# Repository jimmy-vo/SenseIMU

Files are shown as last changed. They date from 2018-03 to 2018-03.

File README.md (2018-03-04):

# SenseIMU
Control a mouse by human gesture via Bluetooth - A demonstration of Kalman Filter and other different optimization and estimation approaches.

## Input
* Accelerometer raw data
* Gyroscope raw data
* Magnetometer raw data

## Output
* Estimated Euler angles
* Estimated Quaternion set
* Represent object orientation on 3D Winform application
* Control mouse using estimated Euler angles via Bluetooth

## Functionality
* Bluetooth Connection
* Data plotting, 3D rendering
* Switching between different algorithms:
  - Tilt-compensation Method  
  - Gauss Newton Method 
  - AHRS
  - Quaternion based – gyro bias – EKF 
  - Quaternion based – gyro rate – EKF
  - DCM based KF 

## Screenshot

### HW Assembly  

<p>
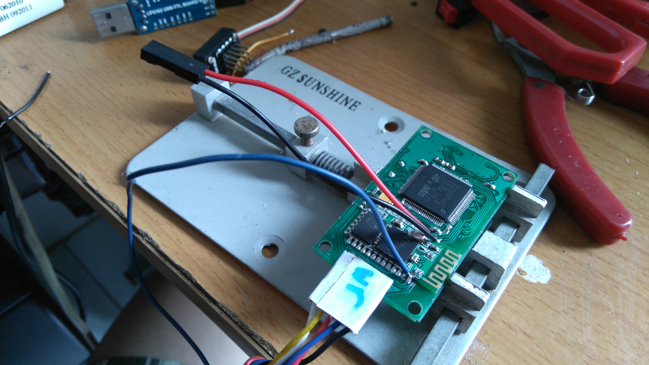
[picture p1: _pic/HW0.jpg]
  
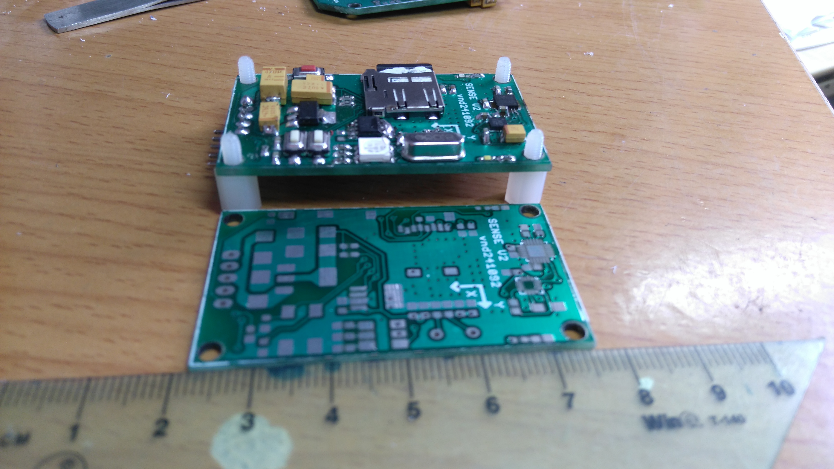
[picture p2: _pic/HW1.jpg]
  
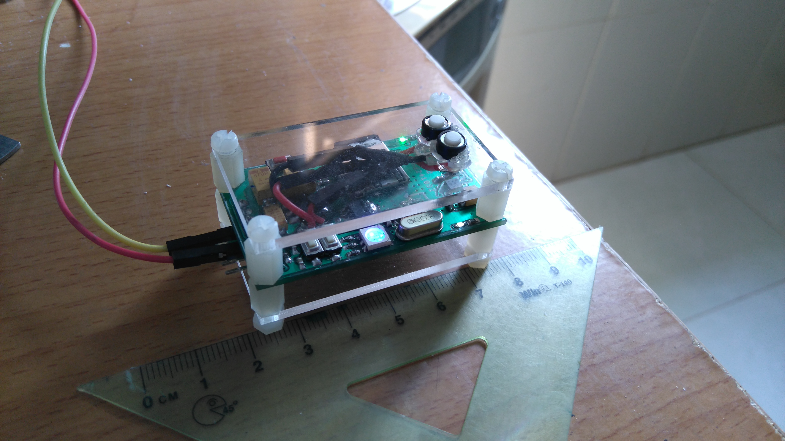
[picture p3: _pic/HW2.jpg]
  
</p>

### Demonstration  
<p>
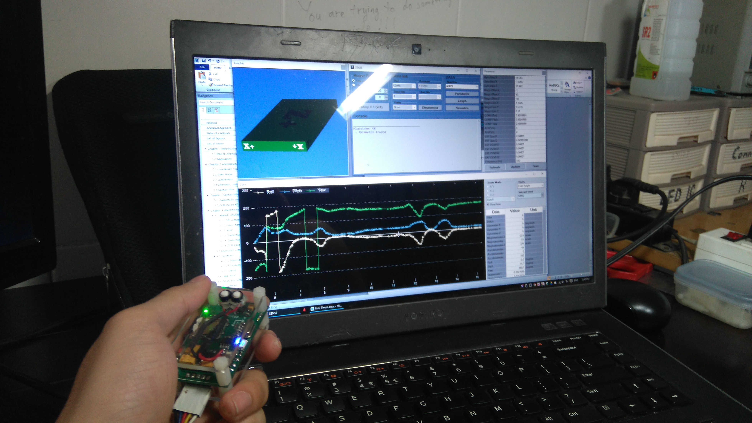
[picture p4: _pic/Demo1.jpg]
  
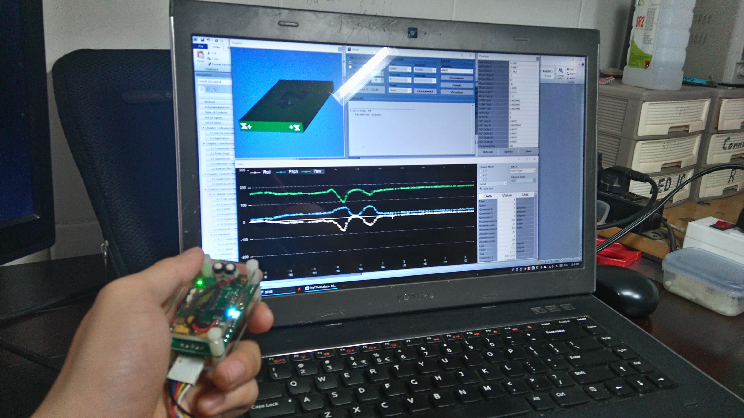
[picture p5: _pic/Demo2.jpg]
  
</p>

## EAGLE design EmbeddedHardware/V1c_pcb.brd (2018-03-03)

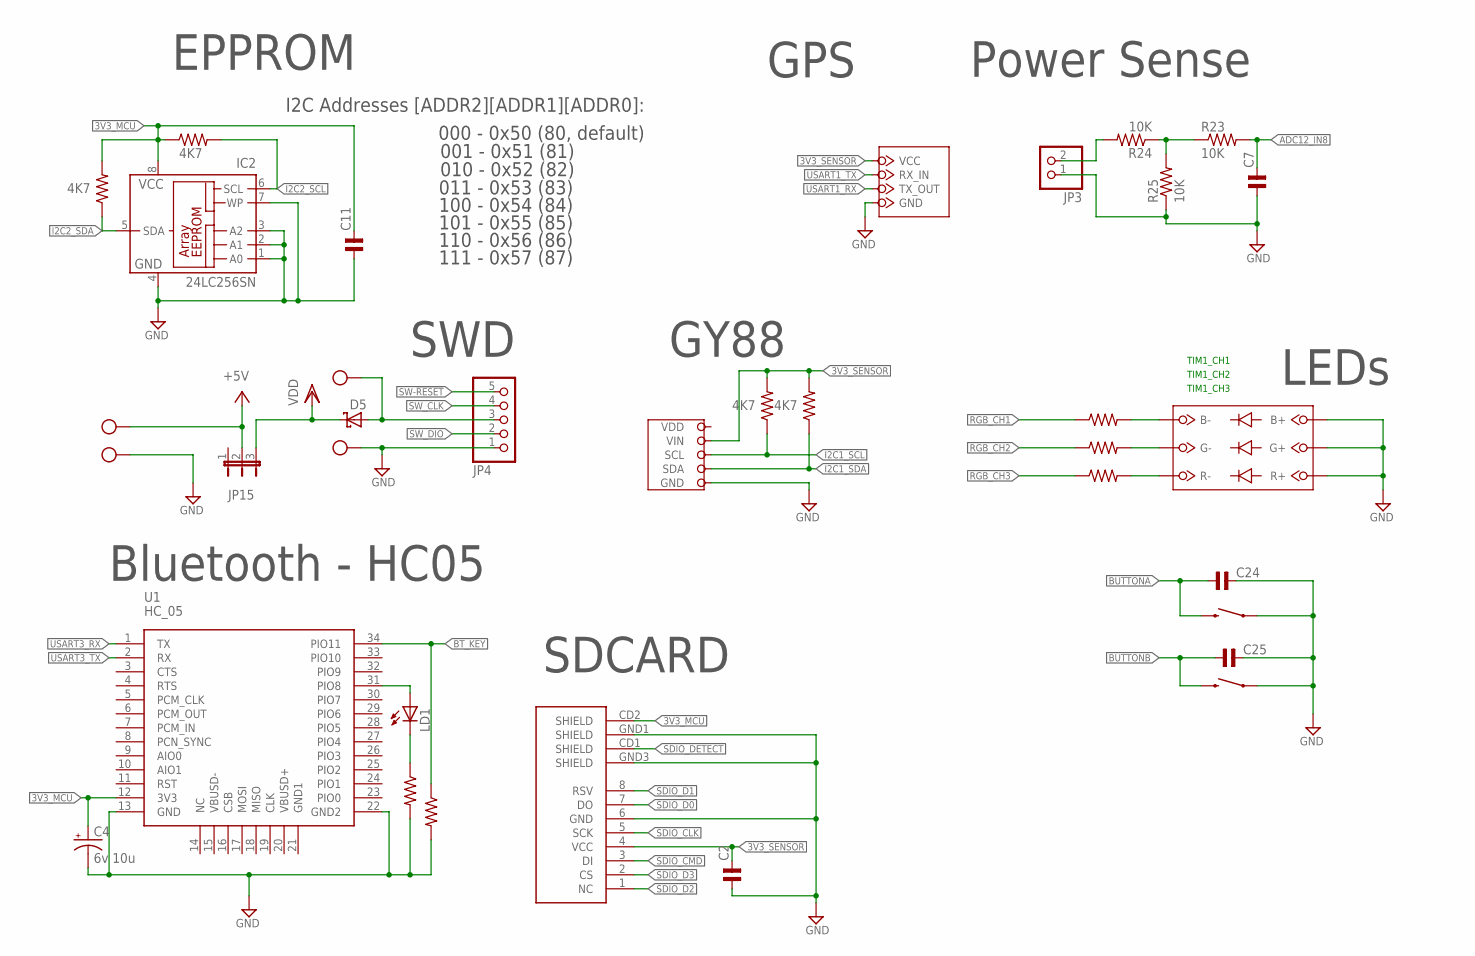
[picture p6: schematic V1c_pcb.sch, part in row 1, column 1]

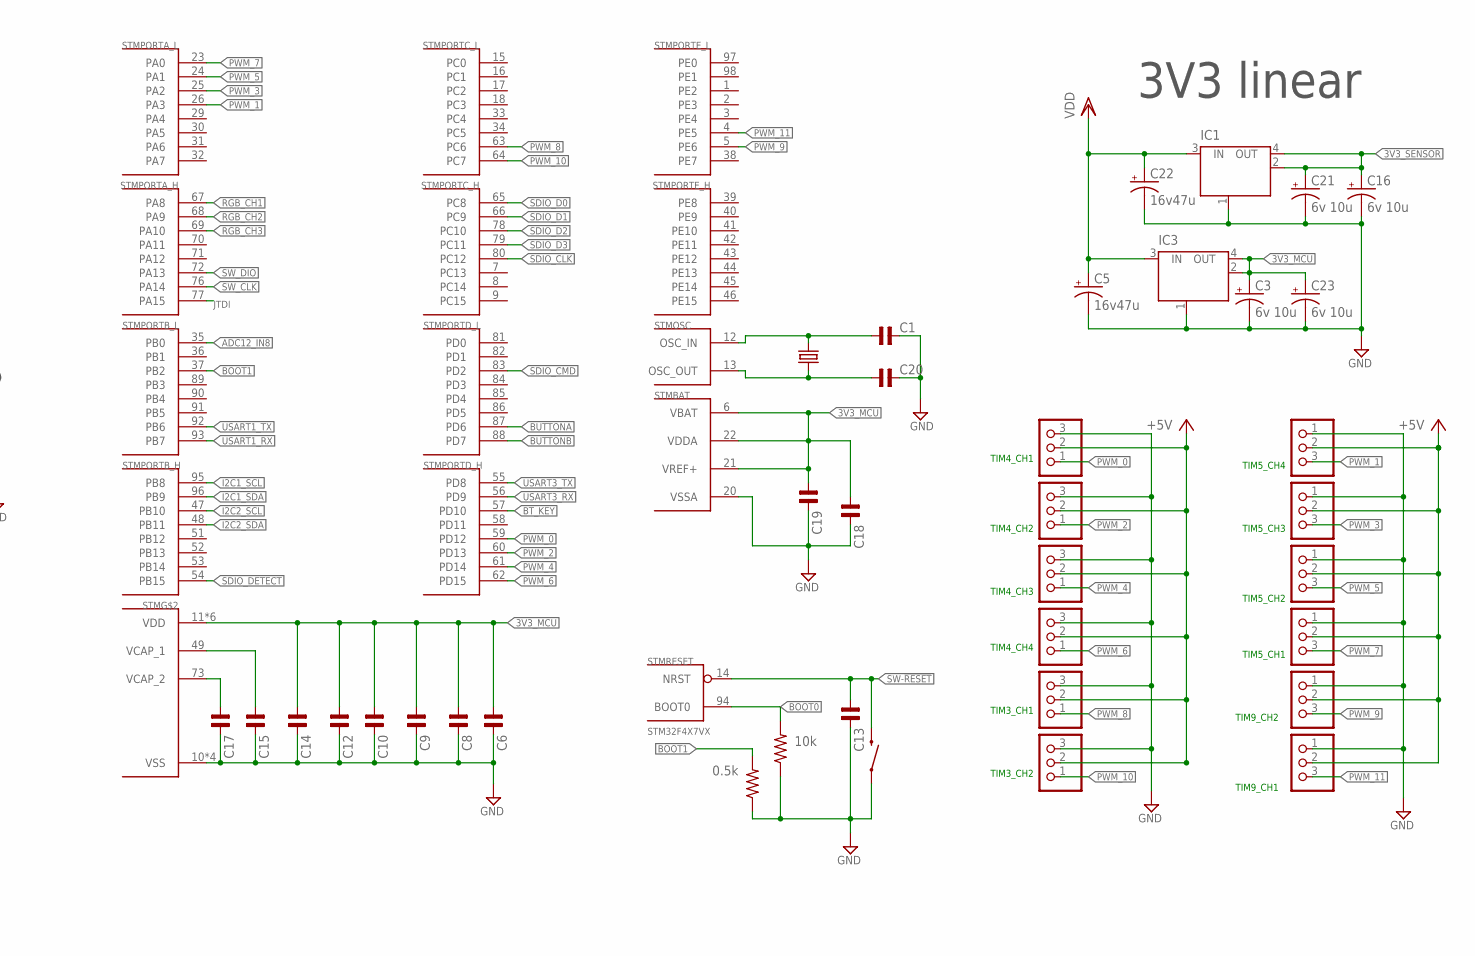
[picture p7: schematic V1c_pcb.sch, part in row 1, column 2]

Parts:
C1, C2, C6, C7, C8, C9, C10, C11, C12, C13, C14, C15, C17, C18, C19, C20, C24, C25: C-NP-SMD-0603; C-0603
C3, C4, C16, C21, C23: 6v 10u; SMC_A
C5, C22: 16v47u; SMC_C
D5: MBRS330T3; SMC
IC1, IC3: LINEAR_MC33269ST-3.3T3; LINEAR_SOT223
IC2: 24LC256SN; SO-08; DIGIKEY 24LC256-E/SN-ND
JP1, JP2, JP5, JP6, JP7, JP8, JP9, JP10, JP11, JP12, JP13, JP14: PINHD-1X3_2.54-90°; 1X03/90
JP3: PINHD-1X2; 1X02
JP4: PINHD-1X5_2.54-90°; 1X05/90
JP15: JP2E; JP2
LD1: LEDCHIPLED_0805; CHIPLED_0805
R1, R4, R15, R16: 4K7; SPARKFUN_0603-RES
R2, R3, R5, R6, R9, R23, R24, R25: 10K; SPARKFUN_0603-RES
R7: 10k; SPARKFUN_0603-RES
R8: 0.5k; SPARKFUN_0603-RES
S1, S2, S3: RESET; TACTILE-SWITCH-1101NE; PARTNO EVQ-P7J01P
SDCARD2: microSD Socket; MICRO-SD-SOCKET-PP
STM: STM32F4X7VX; TQFP100; PARTNO STM32F427VI
U1: HC_05; BLUETOOTH_SMD
U$1: GY-88; BREAKOUT
U$10: GPS_MODULE; 23X30
U$12: RGB_LED; SMD
X1, X2: MKDSN1,5/2-5,08
Y1: CRYSTALHC49US; HC49US

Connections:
3V3_MCU: C3.+, C4.+, C6.1, C8.1, C9.1, C10.1, C11.2, C12.1, C14.1, C18.1, C19.1, C23.+, IC2.8 (VCC), IC3.2 (OUT), IC3.4 (OUT), R15.1, R16.2, SDCARD2.CD2 (SHIELD), STM.6 (VBAT), STM.11 (VDD), STM.19 (VDD), STM.21 (VREF+), STM.22 (VDDA), STM.28 (VDD), STM.50 (VDD), STM.75 (VDD), STM.100 (VDD), U1.12 (3V3)
3V3_SENSOR: C2.2, C16.+, C21.+, IC1.2 (OUT), IC1.4 (OUT), R1.2, R4.2, SDCARD2.4 (VCC), U$1.2 (VIN), U$10.4 (VCC)
+5V: JP1.2, JP2.2, JP5.2, JP6.2, JP7.2, JP8.2, JP9.2, JP10.2, JP11.2, JP12.2, JP13.2, JP14.2, JP15.2, X2.2
ADC12_IN8: C7.2, R23.2, STM.35 (PB0)
BOOT0: R7.2, STM.94 (BOOT0)
BOOT1: R8.2, STM.37 (PB2)
BT_KEY: R5.1, STM.57 (PD10), U1.34 (PIO11)
BUTTONA: C24.1, S3.P$2 (2), STM.87 (PD6)
BUTTONB: C25.1, S2.P$2 (2), STM.88 (PD7)
GND: C1.2, C2.1, C3.-, C4.-, C5.-, C6.2, C7.1, C8.2, C9.2, C10.2, C11.1, C12.2, C13.2, C14.2, C15.2, C16.-, C17.2, C18.2, C19.2, C20.2, C21.-, C22.-, C23.-, C24.2, C25.2, IC1.1 (GND/ADJ), IC2.1 (A0), IC2.2 (A1), IC2.3 (A2), IC2.4 (GND), IC2.7 (WP), IC3.1 (GND/ADJ), JP1.1, JP2.1, JP3.1, JP4.1, JP5.1, JP6.1, JP7.3, JP8.1, JP9.3, JP10.3, JP11.1, JP12.3, JP13.3, JP14.3, R5.2, R7.1, R8.1, R9.2, R25.1, S1.P$1 (1), S2.P$1 (1), S3.P$1 (1), SDCARD2.6 (GND), SDCARD2.GND1 (SHIELD), SDCARD2.GND3 (SHIELD), STM.10 (VSS), STM.20 (VSSA), STM.27 (VSS), STM.74 (VSS), STM.99 (VSS), U1.13 (GND), U1.22 (GND2), U$1.3 (GND), U$10.1 (GND), U$12.B+, U$12.G+, U$12.R+, X1.2, X2.1
I2C1_SCL: R1.1, STM.95 (PB8), U$1.4 (SCL)
I2C1_SDA: R4.1, STM.96 (PB9), U$1.5 (SDA)
I2C2_SCL: IC2.6 (SCL), R15.2, STM.47 (PB10)
I2C2_SDA: IC2.5 (SDA), R16.1, STM.48 (PB11)
JTDI: STM.77 (PA15)
unnamed: C1.1, STM.12 (OSC_IN), Y1.2
unnamed: R2.2, U$12.B-
unnamed: JP3.2, R24.2
unnamed: LD1.A, U1.31 (PIO8)
unnamed: LD1.C, R9.1
unnamed: R3.2, U$12.G-
unnamed: R6.2, U$12.R-
unnamed: D5.A, JP4.3, X1.1
unnamed: R23.1, R24.1, R25.2
unnamed: C20.1, STM.13 (OSC_OUT), Y1.1
unnamed: C17.1, STM.73 (VCAP_2)
unnamed: C15.1, STM.49 (VCAP_1)
PWM_0: JP7.1, STM.59 (PD12)
PWM_1: JP6.3, STM.26 (PA3)
PWM_2: JP9.1, STM.60 (PD13)
PWM_3: JP11.3, STM.25 (PA2)
PWM_4: JP10.1, STM.61 (PD14)
PWM_5: JP5.3, STM.24 (PA1)
PWM_6: JP12.1, STM.62 (PD15)
PWM_7: JP1.3, STM.23 (PA0)
PWM_8: JP13.1, STM.63 (PC6)
PWM_9: JP8.3, STM.5 (PE6)
PWM_10: JP14.1, STM.64 (PC7)
PWM_11: JP2.3, STM.4 (PE5)
RGB_CH1: R2.1, STM.67 (PA8)
RGB_CH2: R3.1, STM.68 (PA9)
RGB_CH3: R6.1, STM.69 (PA10)
SDIO_CLK: SDCARD2.5 (SCK), STM.80 (PC12)
SDIO_CMD: SDCARD2.3 (DI), STM.83 (PD2)
SDIO_D0: SDCARD2.7 (DO), STM.65 (PC8)
SDIO_D1: SDCARD2.8 (RSV), STM.66 (PC9)
SDIO_D2: SDCARD2.1 (NC), STM.78 (PC10)
SDIO_D3: SDCARD2.2 (CS), STM.79 (PC11)
SDIO_DETECT: SDCARD2.CD1 (SHIELD), STM.54 (PB15)
SW-!RESET: C13.1, JP4.5, S1.P$2 (2), STM.14 (NRST)
SW_CLK: JP4.4, STM.76 (PA14)
SW_DIO: JP4.2, STM.72 (PA13)
USART1_RX: STM.93 (PB7), U$10.2 (TX_OUT)
USART1_TX: STM.92 (PB6), U$10.3 (RX_IN)
USART3_RX: STM.56 (PD9), U1.1 (TX)
USART3_TX: STM.55 (PD8), U1.2 (RX)
VDD: C5.+, C22.+, D5.C, IC1.3 (IN), IC3.3 (IN), JP15.3

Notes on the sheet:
SWD
LEDs
GPS
GY88
TIM5_CH1
TIM5_CH2
TIM1_CH1
TIM1_CH2
TIM1_CH3
TIM4_CH1
TIM4_CH2
I2C Addresses [ADDR2][ADDR1][ADDR0]:
000 - 0x50 (80, default)
001 - 0x51 (81)
010 - 0x52 (82)
011 - 0x53 (83)
100 - 0x54 (84)
101 - 0x55 (85)
110 - 0x56 (86)
111 - 0x57 (87)
EPPROM
TIM5_CH3
TIM5_CH4
Bluetooth - HC05
SDCARD
Power Sense
TIM4_CH4
TIM4_CH3
TIM9_CH2
TIM9_CH1
TIM3_CH1
TIM3_CH2
3V3 linear

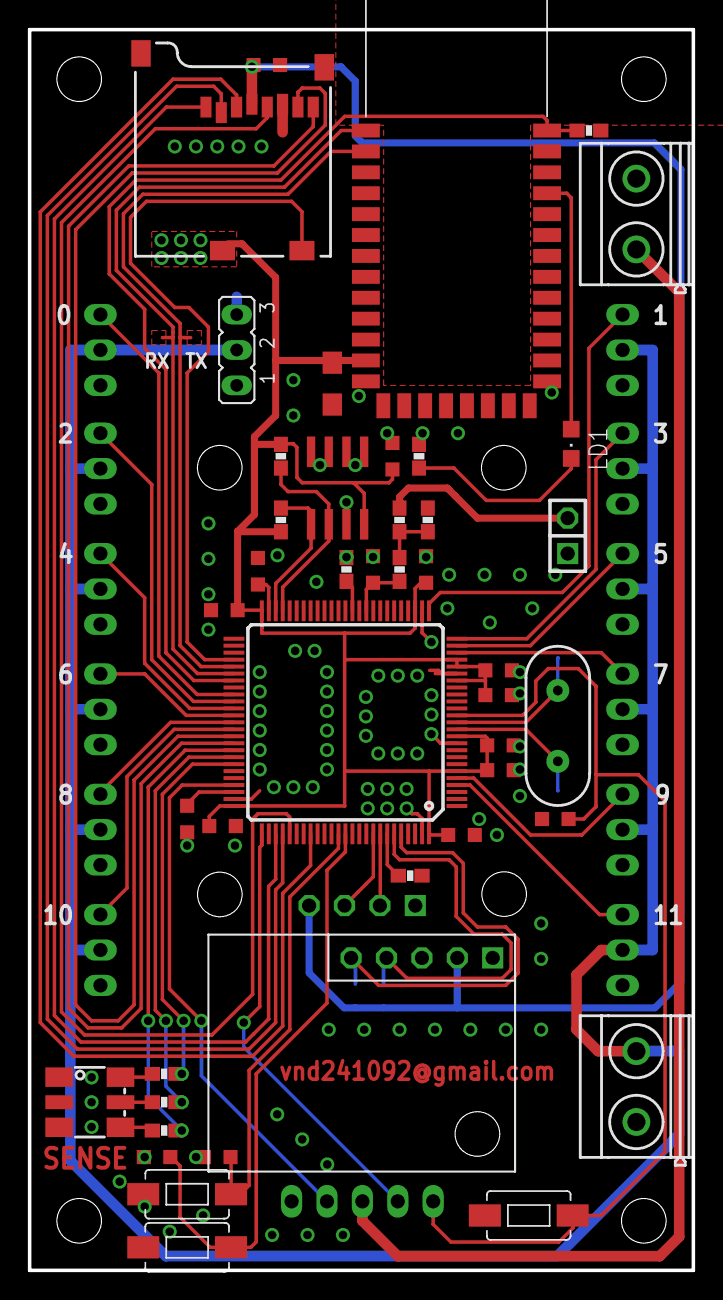
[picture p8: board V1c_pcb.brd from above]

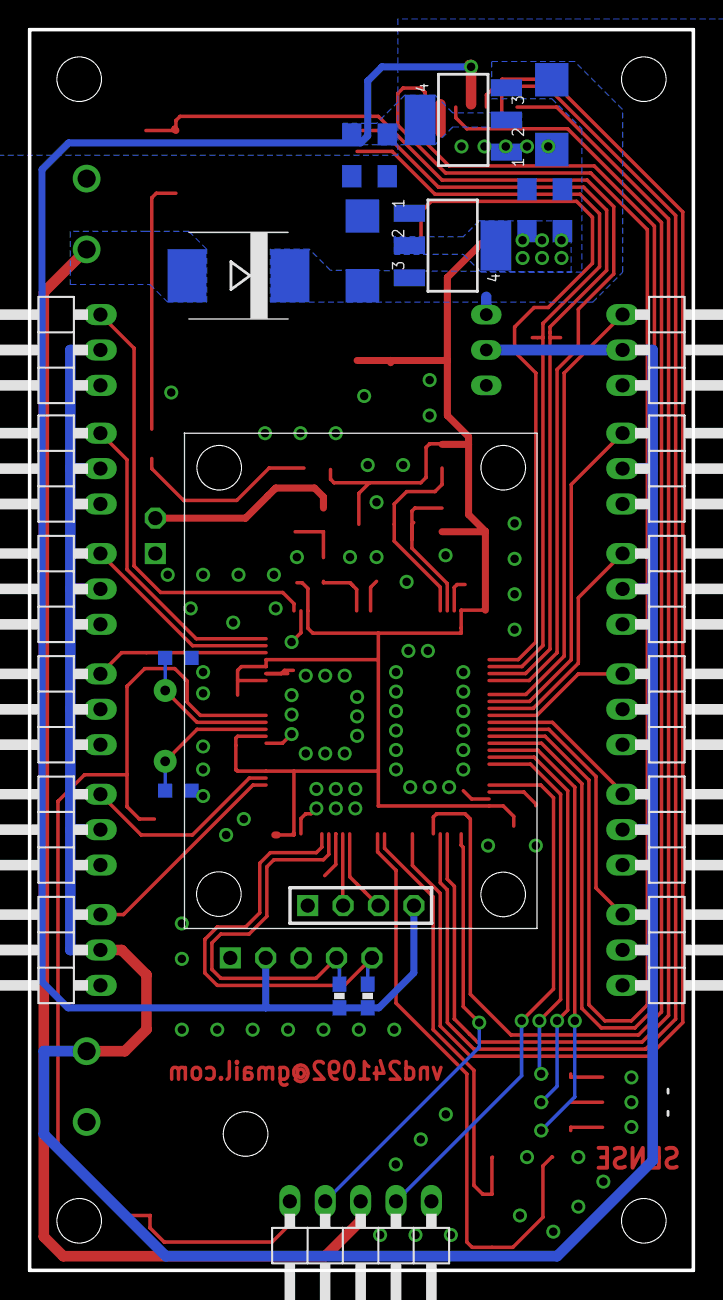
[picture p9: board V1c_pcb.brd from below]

Board: 2 copper layers, 47.6 x 89.0 mm, 71 parts (27 on the bottom side), 56 nets.

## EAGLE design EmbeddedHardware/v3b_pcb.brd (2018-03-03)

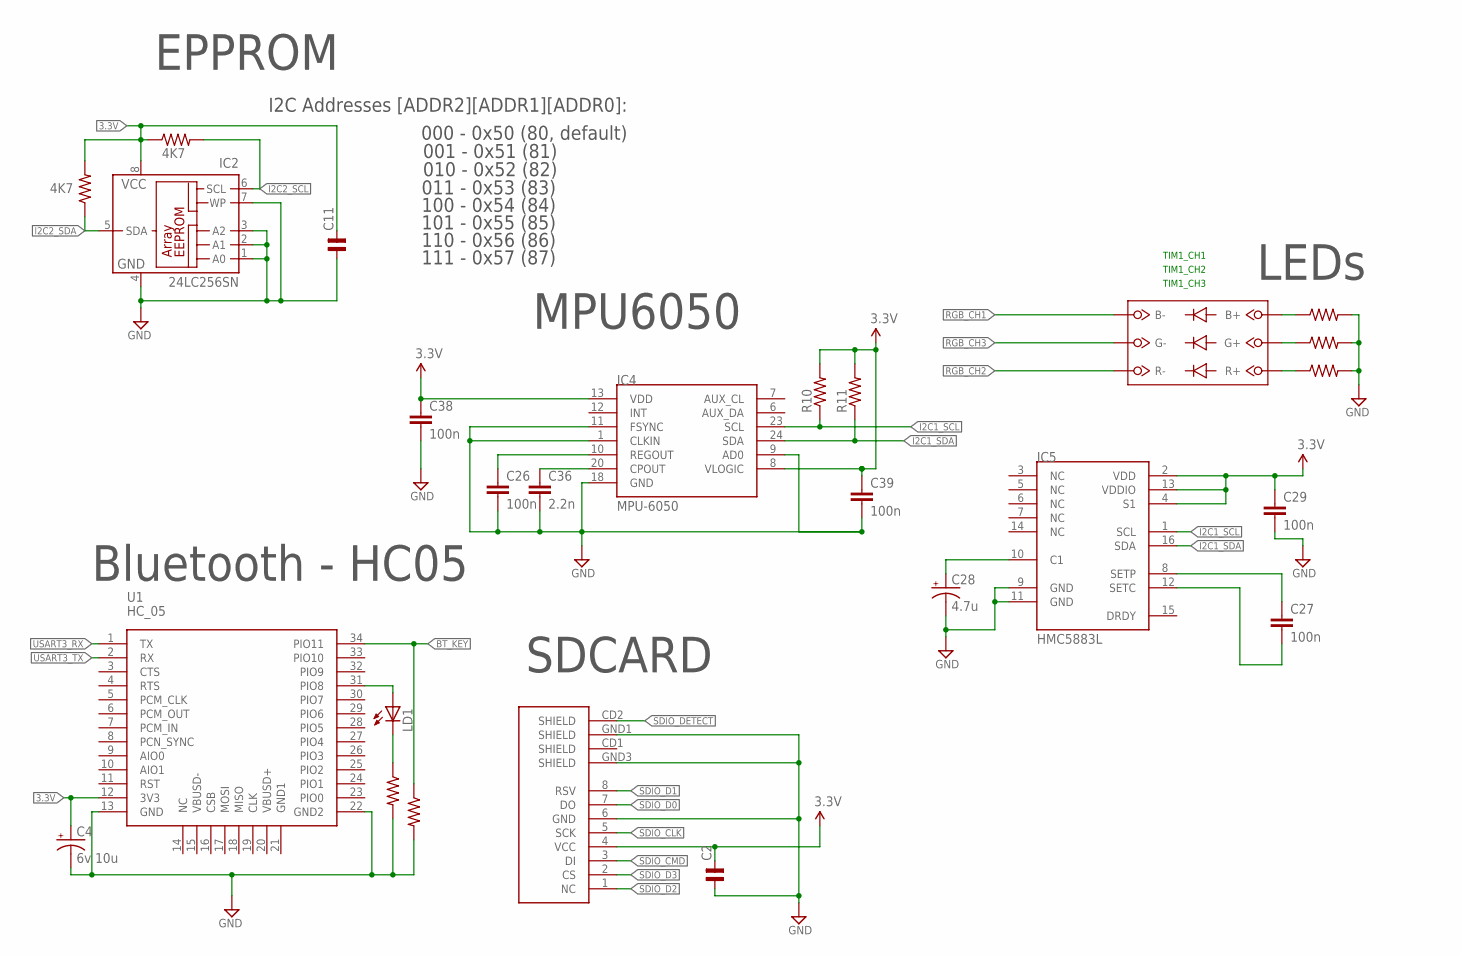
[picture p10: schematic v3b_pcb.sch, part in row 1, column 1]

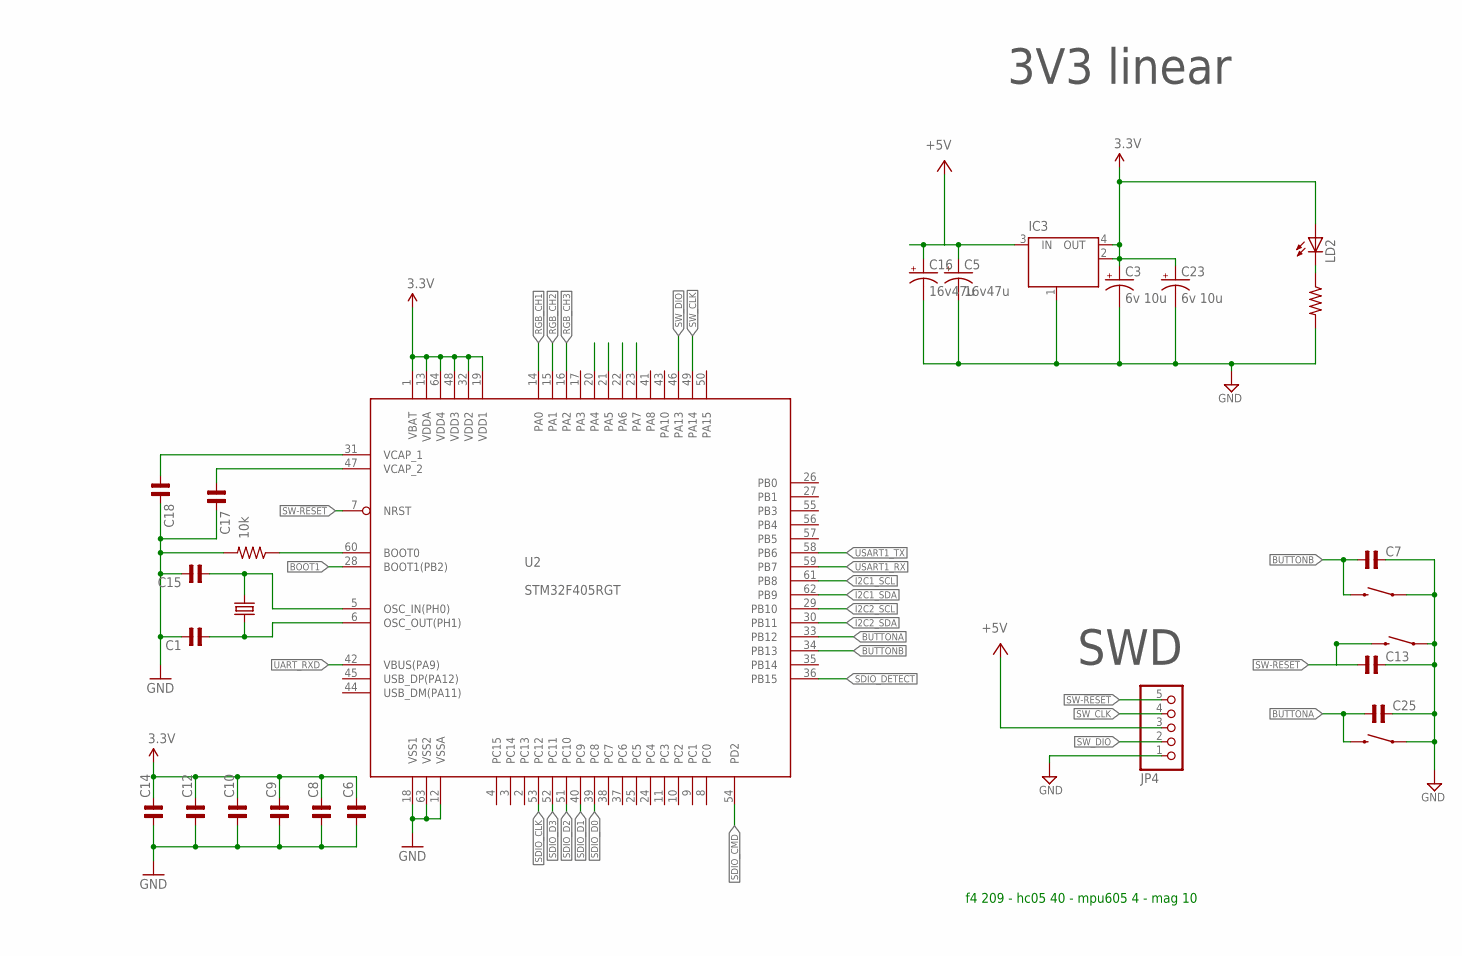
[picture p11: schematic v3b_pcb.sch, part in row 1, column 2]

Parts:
C1, C2, C6, C7, C8, C9, C10, C11, C12, C13, C14, C15, C17, C18, C25: C-NP-SMD-0603; C-0603
C3, C23: 6v 10u; SMC_C
C4: 6v 10u; SMC_A
C5, C16: 16v47u; SMC_C
C26, C27, C29, C38, C39: 100n; SPARKFUN_0603-CAP
C28: 4.7u; SMC_A
C36: 2.2n; SPARKFUN_0603-CAP
IC2: 24LC256SN; SO-08; DIGIKEY 24LC256-E/SN-ND
IC3: LINEAR_MC33269ST-3.3T3; LINEAR_SOT223
IC4: MPU-6050; TESTING_QFN-24-4MM2
IC5: HMC5883L; SPARKFUN_16LPCC
JP4: PINHD-1X5_2.54-90°; 1X05/90
LD1, LD2: LEDCHIPLED_0603; CHIPLED_0603
R1, R2, R3, R5, R6, R9: 10K; SPARKFUN_0603-RES
R7: 10k; SPARKFUN_0603-RES
R10, R11: SPARKFUN_RESISTOR0603-RES; SPARKFUN_0603-RES
R15, R16: 4K7; SPARKFUN_0603-RES
S1, S2, S4: RESET; TACTILE-SWITCH-1101NE; PARTNO EVQ-P7J01P
SDCARD2: microSD Socket; MICRO-SD-SOCKET-PP
U1: HC_05; BLUETOOTH_SMD
U2: STM32F405RGT; LQFP64
U$12: RGB_LED; SMD
Y2: CRYSTALHC49US; HC49US

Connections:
3.3V: C2.2, C3.+, C4.+, C6.2, C8.2, C9.2, C10.2, C11.2, C12.2, C14.2, C23.+, C29.1, C38.1, C39.1, IC2.8 (VCC), IC3.2 (OUT), IC3.4 (OUT), IC4.8 (VLOGIC), IC4.13 (VDD), IC5.2 (VDD), IC5.4 (S1), IC5.13 (VDDIO), LD2.A, R10.2, R11.2, R15.1, R16.2, SDCARD2.4 (VCC), U1.12 (3V3), U2.1 (VBAT), U2.13 (VDDA), U2.19 (VDD1), U2.32 (VDD2), U2.48 (VDD3), U2.64 (VDD4)
+5V: C5.+, C16.+, IC3.3 (IN), JP4.3
BOOT0: R7.1, U2.60 (BOOT0)
BOOT1: U2.28 (BOOT1(PB2))
BT_KEY: R5.1, U1.34 (PIO11)
BUTTONA: C25.1, S2.P$2 (2), U2.33 (PB12)
BUTTONB: C7.1, S4.P$2 (2), U2.34 (PB13)
GND: C1.2, C2.1, C3.-, C4.-, C5.-, C6.1, C7.2, C8.1, C9.1, C10.1, C11.1, C12.1, C13.2, C14.1, C15.2, C16.-, C17.2, C18.2, C23.-, C25.2, C26.2, C28.-, C29.2, C36.2, C38.2, C39.2, IC2.1 (A0), IC2.2 (A1), IC2.3 (A2), IC2.4 (GND), IC2.7 (WP), IC3.1 (GND/ADJ), IC4.1 (CLKIN), IC4.9 (AD0), IC4.11 (FSYNC), IC4.18 (GND), IC5.9 (GND), IC5.11 (GND), JP4.1, R1.2, R2.2, R3.2, R5.2, R6.2, R7.2, R9.2, S1.P$1 (1), S2.P$1 (1), S4.P$1 (1), SDCARD2.6 (GND), SDCARD2.GND1 (SHIELD), SDCARD2.GND3 (SHIELD), U1.13 (GND), U1.22 (GND2), U2.12 (VSSA), U2.18 (VSS1), U2.63 (VSS2)
I2C1_SCL: IC4.23 (SCL), IC5.1 (SCL), R10.1, U2.61 (PB8)
I2C1_SDA: IC4.24 (SDA), IC5.16 (SDA), R11.1, U2.62 (PB9)
I2C2_SCL: IC2.6 (SCL), R15.2, U2.29 (PB10)
I2C2_SDA: IC2.5 (SDA), R16.1, U2.30 (PB11)
MISO: U2.22 (PA6)
MOSI: U2.23 (PA7)
unnamed: R2.1, U$12.B+
unnamed: C26.1, IC4.10 (REGOUT)
unnamed: LD1.A, U1.31 (PIO8)
unnamed: LD1.C, R9.1
unnamed: R6.1, U$12.R+
unnamed: R3.1, U$12.G+
unnamed: C36.1, IC4.20 (CPOUT)
unnamed: C27.1, IC5.8 (SETP)
unnamed: LD2.C, R1.1
unnamed: C28.+, IC5.10 (C1)
unnamed: C27.2, IC5.12 (SETC)
unnamed: C15.1, U2.5 (OSC_IN(PH0)), Y2.2
unnamed: C1.1, U2.6 (OSC_OUT(PH1)), Y2.1
unnamed: C18.1, U2.31 (VCAP_1)
unnamed: C17.1, U2.47 (VCAP_2)
NSS: U2.20 (PA4)
RGB_CH1: U2.14 (PA0), U$12.B-
RGB_CH2: U2.15 (PA1), U$12.R-
RGB_CH3: U2.16 (PA2), U$12.G-
SCK: U2.21 (PA5)
SDIO_CLK: SDCARD2.5 (SCK), U2.53 (PC12)
SDIO_CMD: SDCARD2.3 (DI), U2.54 (PD2)
SDIO_D0: SDCARD2.7 (DO), U2.39 (PC8)
SDIO_D1: SDCARD2.8 (RSV), U2.40 (PC9)
SDIO_D2: SDCARD2.1 (NC), U2.51 (PC10)
SDIO_D3: SDCARD2.2 (CS), U2.52 (PC11)
SDIO_DETECT: SDCARD2.CD2 (SHIELD), U2.36 (PB15)
SW-!RESET: C13.1, JP4.5, S1.P$2 (2), U2.7 (NRST)
SW_CLK: JP4.4, U2.49 (PA14)
SW_DIO: JP4.2, U2.46 (PA13)
UART_RXD: U2.42 (VBUS(PA9))
USART1_RX: U2.59 (PB7)
USART1_TX: U2.58 (PB6)
USART3_RX: U1.1 (TX)
USART3_TX: U1.2 (RX)

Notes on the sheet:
SWD
LEDs
TIM1_CH1
TIM1_CH2
TIM1_CH3
I2C Addresses [ADDR2][ADDR1][ADDR0]:
000 - 0x50 (80, default)
001 - 0x51 (81)
010 - 0x52 (82)
011 - 0x53 (83)
100 - 0x54 (84)
101 - 0x55 (85)
110 - 0x56 (86)
111 - 0x57 (87)
EPPROM
Bluetooth - HC05
SDCARD
3V3 linear
MPU6050
f4 209 - hc05 40 - mpu605 4 - mag 10

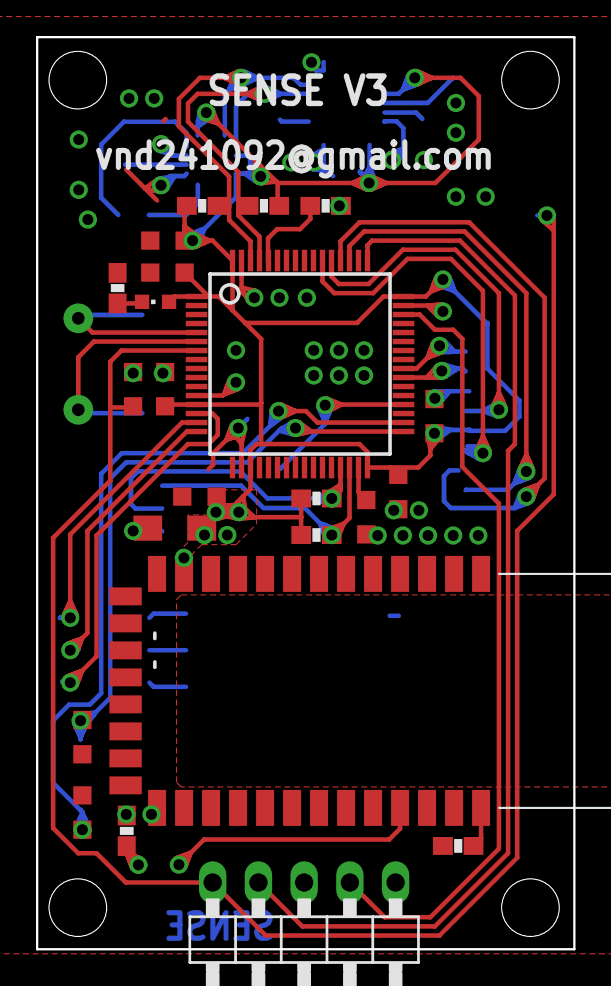
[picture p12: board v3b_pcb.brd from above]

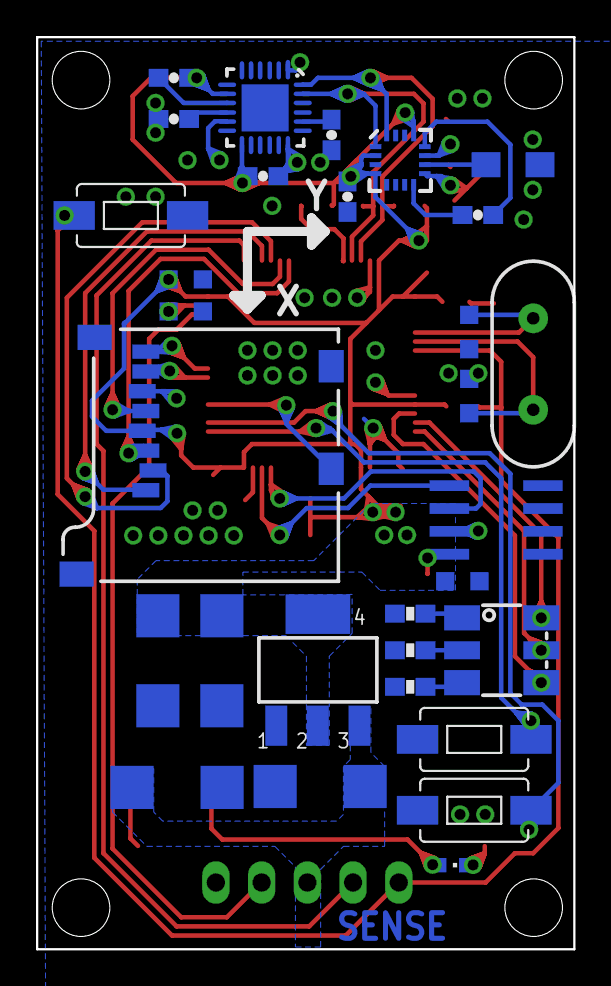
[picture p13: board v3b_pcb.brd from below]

Board: 2 copper layers, 29.8 x 50.7 mm, 53 parts (30 on the bottom side), 39 nets.

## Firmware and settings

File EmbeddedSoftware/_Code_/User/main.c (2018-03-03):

#include "BoardConfig.h"
#include "INCLUDE.h"
#include <math.h>
#include <stdio.h>
#include <stdlib.h>
#include "misc.h"

int main(void)
{
	Initialize_SerialLink();	
	
	Initialize_Timer();	
	
	Initialize_PARAMETER(1);	
	
	Button_Initialize();
	
	RGB_Initialize();	
	
	Voltage_FB_Initiallize();	
	
	while (1)
		{
			switch (SerialLink_GetCMD())
			{
				case INPUT_CMD_ParamBoardtoPC: 
																				PARAM_EEPROM_READ();	
																				SerialLink_SendParameter();				
																				SerialLink_ResetCMD();																					
																				break;
				case INPUT_CMD_ParamSaveEPPROM: 
																				PARAM_EEPROM_WRITE(PARA_TYPE_MAX);		
																				SerialLink_ResetCMD();
																				break;	
				case INPUT_CMD_Calib: 
																				CALIB_Calibrate(5*1000*60,0,1);	
																				SerialLink_ResetCMD();
																				Algorithm_Reset();
																				break;	
				case INPUT_CMD_None: 
																				Algorithm_Orientiation();
																				break;	
				default: 											
																				Algorithm_Switch((ALGORITHM)SerialLink_GetCMD());
																				SerialLink_ResetCMD();
																				break;	
			}
		}
}

void HardFault_Handler(void)
{	
  while (1);
}

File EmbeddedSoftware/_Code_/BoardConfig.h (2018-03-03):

#include "stm32f4xx_conf.h"
extern uint8_t shutdown;

				////////////////////////////////////////////DMA 1 Interupt is used////////////////////////////////////////
			 //  Stream0  //  Stream1  //  Stream2  //  Stream3  //  Stream4  //  Stream5  //  Stream6  //  Stream7  //                                      
			//////////////////////////////////////////////////////////////////////////////////////////////////////////
		 // Channel1  //  Channel4 //  Channel7 //  Channel4 // 				  //  Channel1 //  Channel1 //  Channel7 //                                        
		//////////////////////////////////////////////////////////////////////////////////////////////////////////
	 // I2C1-RX   //  UART3-RX //  I2C2-RX  //  UART3-TX // 				  //  UART1-RX //  I2C1-TX	//  I2C2-TX  //                                     
	//////////////////////////////////////////////////////////////////////////////////////////////////////////

			////////////////////////////////////////////DMA 1 Interupt is used////////////////////////////////////////
		 //  Stream0  //  Stream1  //  Stream2  //  Stream3  //  Stream4  //  Stream5  //  Stream6  //  Stream7  //                                      
		//////////////////////////////////////////////////////////////////////////////////////////////////////////
	 //           // 	 ADC3	 	 //           //           //           //           //           //           //                                      
	//////////////////////////////////////////////////////////////////////////////////////////////////////////
 //           // 	Channel4 //           //           //           //           //           //           //                                        
//////////////////////////////////////////////////////////////////////////////////////////////////////////


#define NVIC_GROUP_DEFAULT 													NVIC_PriorityGroup_3		//3 bit pre-emption


#define NVIC_Prepriority_systick 						6
#define NVIC_Subpriority_systick 						0

#define NVIC_Prepriority_SerialLink					7
#define NVIC_Subpriority_SerialLink 				0

#define NVIC_Prepriority_GPS		 						0
#define NVIC_Subpriority_GPS 								0

#define NVIC_Prepriority_SENSOR 						4
#define NVIC_Subpriority_SENSOR 						0

#define NVIC_Prepriority_SDIO		 						3
#define NVIC_Subpriority_SDIO		 						0

#define NVIC_Prepriority_EPPROM	 						2
#define NVIC_Subpriority_EPPROM 						0

  /////////////////////////////////////////////////////////////////
 //										ADC_Voltage_Feedback											//	
/////////////////////////////////////////////////////////////////
#define VoltFB_GPIO_PORT						GPIOC
#define VoltFB_GPIO_PIN 						GPIO_Pin_0
#define VoltFB_GPIO_CLK  						RCC_AHB1Periph_GPIOC

#define VoltFB_ADC  					  		ADC1
#define VoltFB_ADC_CLK  						RCC_APB2Periph_ADC1
#define VoltFB_ADC_CHANNEL  				ADC_Channel_10

/////////////////////////////////////////////////////////////////

  /////////////////////////////////////////////////////////////////
 //														USART1														//									
/////////////////////////////////////////////////////////////////
#define UART1_GPIO_PORT					GPIOB
#define UART1_GPIO_CLK					RCC_AHB1Periph_GPIOB

#define UART1_IRQn							USART1_IRQn
#define UART1_IT								USART1_IRQHandler

#define UART1_TX_PIN						GPIO_Pin_6
#define UART1_TX_SOURCE					GPIO_PinSource6
#define UART1_RX_PIN						GPIO_Pin_7
#define UART1_RX_SOURCE					GPIO_PinSource7

#define UART1_TX_DMA_CH					DMA_Channel_4
#define UART1_TX_DMA_ST					DMA2_Stream7
#define UART1_TX_DMA_IRQn				DMA2_Stream7_IRQn
#define UART1_TX_DMA_FLAG				DMA_IT_TCIF7
#define UART1_TX_DMA_IT					DMA2_Stream7_IRQHandler

#define UART1_RX_DMA_CH					DMA_Channel_4
#define UART1_RX_DMA_ST					DMA2_Stream2
#define UART1_RX_DMA_IRQn				DMA2_Stream2_IRQn
#define UART1_RX_DMA_FLAG				DMA_IT_TCIF2
#define UART1_RX_DMA_IT					DMA2_Stream2_IRQHandler
/////////////////////////////////////////////////////////////////
									
  /////////////////////////////////////////////////////////////////
 //														USART3														//									
/////////////////////////////////////////////////////////////////
#define UART3_GPIO_PORT					GPIOD
#define UART3_GPIO_CLK					RCC_AHB1Periph_GPIOD

#define UART3_IRQn							USART3_IRQn
#define UART3_IT								USART3_IRQHandler

#define UART3_RX_PIN						GPIO_Pin_9
#define UART3_RX_SOURCE					GPIO_PinSource9
#define UART3_TX_PIN						GPIO_Pin_8
#define UART3_TX_SOURCE					GPIO_PinSource8

#define UART3_RX_DMA_CH					DMA_Channel_4
#define UART3_RX_DMA_ST					DMA1_Stream1
#define UART3_RX_DMA_IRQn				DMA1_Stream1_IRQn
#define UART3_RX_DMA_FLAG				DMA_IT_TCIF1
#define UART3_RX_DMA_IT					DMA1_Stream1_IRQHandler

#define UART3_TX_DMA_CH					DMA_Channel_4
#define UART3_TX_DMA_ST					DMA1_Stream3
#define UART3_TX_DMA_IRQn				DMA1_Stream3_IRQn
#define UART3_TX_DMA_FLAG				DMA_IT_TCIF3
#define UART3_TX_DMA_IT					DMA1_Stream3_IRQHandler
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

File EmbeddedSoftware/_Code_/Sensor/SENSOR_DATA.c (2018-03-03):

#include "Button.h"
#include "MPU6050.h"
#include "HMC5883L.h"
#include "RGB.h"
#include "Timing_Manage.h"
#include "Computation.h"
#include "SENSOR_DATA.h"
#include "Voltage_FB.h"
#include "Serial_Link.h"
#include "Parameter.h"
#include "Dev_I2C.h"
#include <math.h>
#include <stdio.h>
#include <stdlib.h>
#include "ff.h"

/////////////////////////////////////////////////////////////////////////////////////////////////////////////////////////////////
////Variable
//
static uint64_t SENSOR_Lastime;
static  uint16_t 	Framecount = 0;
/////////////////////////////////////////////////////////////////////////////////////////////////////////////////////////////////
////extern global term	
//
float_3D 		MagScalerGain, MagOffset, MagAxis, GyroBias;

float 			EKFQUA_r; 
float 			EKFQUA_q;
float 			KFDCM_r1; 
float 			KFDCM_q1;
float 			KFDCM_r2; 
float 			KFDCM_q2;
float 			Thres_Acce; 
float 			Thres_Gyro;
float 			aKFDCM_r1; 
float 			aKFDCM_q1;
float 			aKFDCM_r2; 
float 			aKFDCM_q2;

float_3D 	Comp; 
float 			SenseFreq = 500, SenseBat;
float 			AHRS_Kp, AHRS_Ki;
/////////////////////////////////////////////////////////////////////////////////////////////////////////////////////////////////
////Driver
//
static void SENSOR_delay(u32 nCount)
{
	Delay_ms(nCount);
}

SENSOR_Status Initialize_SENSOR_Bus (void)
{
	GPIO_InitTypeDef  GPIO_InitStructure;
	
	/* GPIO Periph clock enable */
	RCC_AHB1PeriphClockCmd(I2C1_GPIO_CLK, ENABLE);

	/* Configure I2C2 pins: SCL and SDA */
	GPIO_InitStructure.GPIO_Pin 		=  	I2C1_SCL_PIN | I2C1_SDA_PIN;
	GPIO_InitStructure.GPIO_Mode 		= 	GPIO_Mode_AF;
	GPIO_InitStructure.GPIO_Speed 	= 	GPIO_Speed_100MHz;
	GPIO_InitStructure.GPIO_OType 	= 	GPIO_OType_OD;
	GPIO_InitStructure.GPIO_PuPd  	= 	GPIO_PuPd_NOPULL;
	GPIO_Init(I2C1_GPIO_PORT, &GPIO_InitStructure);

	/* Connect GPIO pins to peripheral */
	GPIO_PinAFConfig(I2C1_GPIO_PORT, I2C1_SCL_SOURCE, I2C1_AF); 
	GPIO_PinAFConfig(I2C1_GPIO_PORT, I2C1_SDA_SOURCE, I2C1_AF);

	IMU.TX.DMA									= I2C_DMA_Enable;
	IMU.TX.DMA_Channel					=	I2C1_TX_DMA_CH;
	IMU.TX.DMA_Stream						=	I2C1_TX_DMA_ST;
	IMU.TX.DMA_Flag							=	I2C1_TX_DMA_FLAG;
	IMU.TX.DMA_NVIC_IRQ					=	I2C1_TX_DMA_IRQn;
	IMU.TX.SubPri								=	NVIC_Subpriority_SENSOR;
	IMU.TX.preemtionPri					=	NVIC_Prepriority_SENSOR;

	IMU.RX.DMA									= I2C_DMA_Enable;
	IMU.RX.DMA_Channel					=	I2C1_RX_DMA_CH;
	IMU.RX.DMA_Stream						=	I2C1_RX_DMA_ST;
	IMU.RX.DMA_Flag							=	I2C1_RX_DMA_FLAG;
	IMU.RX.DMA_NVIC_IRQ					=	I2C1_RX_DMA_IRQn;
	IMU.TX.SubPri								=	NVIC_Subpriority_SENSOR;
	IMU.TX.preemtionPri					=	NVIC_Prepriority_SENSOR+1;
	
	IMU.TimeOut 									= 100;		//10ms
	IMU.I2C											= I2C1;		
	
	Initialize_I2C(&IMU,400000);			//400kHz
			
	SENSOR_delay(100);		

	if(MPU6050_ConnectionCheck()	==	MPU6050_STATUS_OK)	
		{	 				
			if	(MPU6050_Set_PWR_MGMT_1(EKFQUA_MPU6050_SleepMode, EKFQUA_MPU6050_Temperature, EKFQUA_MPU6050_Clock)!= MPU6050_STATUS_OK)
				return SENSOR_SETUP_MPU6050_Fail;		
				
			if	(	MPU6050_Set_GYRO_Config(EKFQUA_GYRO_FullScaleRange)!= MPU6050_STATUS_OK) 
				return SENSOR_SETUP_MPU6050_Fail;		
				
			if	(MPU6050_Set_ACCEL_Config(EKFQUA_ACCEL_FullScaleRange)!= MPU6050_STATUS_OK) 
				return SENSOR_SETUP_MPU6050_Fail;		
				
			if	(MPU6050_Set_Configuration(EKFQUA_MPU6050_DLPF_CFG)!= MPU6050_STATUS_OK)	
				return SENSOR_SETUP_MPU6050_Fail;		
				
			if	(	MPU6050_Set_SMPLRT_DIV(EKFQUA_MPU6050_SMPLRT_DIV)!= MPU6050_STATUS_OK)	
				return SENSOR_SETUP_MPU6050_Fail;		
		}		
//		
	if(HMC5883_ConnectionCheck() == HMC5883_STATUS_OK)
		{
			if(HMC5883_Configuration_A(EKFQUA_HMC5883_AVERAGE, EKFQUA_HMC5883_RATE, EKFQUA_HMC5883_BIAS)!= I2C_STATUS_OK)		
				return	SENSOR_SETUP_HMC5883_Fail;					
			if(HMC5883_Configuration_B(EKFQUA_HMC5883_GAIN)!= I2C_STATUS_OK)																									
				return	SENSOR_SETUP_HMC5883_Fail;	
			if(HMC5883_Configuration_MODE(EKFQUA_HMC5883_HIGHSPEED, EKFQUA_HMC5883_MODE)!= I2C_STATUS_OK)				
				return	SENSOR_SETUP_HMC5883_Fail;	
		}		
		
	return SENSOR_OK;
}

SENSOR_Status SENSOR_Update_Data (float_3D *Acce, float_3D *Gyro, float_3D *Magn, float *Temp, float32_t *SampleTime)
{
	SENSOR_Status READ = SENSOR_OK;
	static int16_t mx, my, mz;
	static int16_t ax, ay, az;
	static int16_t gx, gy, gz;
	static float_3D mag;
	static DCM R;
	/////////////////////////////////////////////////
	//	Calculate dt
	//	
	uint64_t Time = Get_usTick();
	(*SampleTime) = ((float32_t)(Time - SENSOR_Lastime))/1000000.0f;
	SENSOR_Lastime = Time;	

	/////////////////////////////////////////////////
	//	Sampling
	//
	if (MPU6050_Get_rawDATA (&gx, &gy, &gz, &ax, &ay, &az, Temp) != MPU6050_STATUS_OK)
		READ = SENSOR_READ_MPU6050_Fail;
	if (HMC5883_Get_RawMagn (&mx, &my, &mz)!= HMC5883_STATUS_OK)
		READ = SENSOR_READ_HMC5883_Fail;
	/////////////////////////////////////////////////
	//	Magn
	//add offset and scale to circle				
	Magn->x = 	((MagOffset.x + (float)mx) *	 MagScalerGain.x);
	Magn->y = 	((MagOffset.y + (float)my) *	 MagScalerGain.y);
	Magn->z = 	((MagOffset.z + (float)mz) *	 MagScalerGain.z);
	
	//rotate axis	
//	Convert_DEG_Dcm(&MagAxis, &R);	
//	Magn->x = mag.x*R.dcm0 + mag.y*R.dcm1 + mag.z*R.dcm2;
//	Magn->y = mag.x*R.dcm3 + mag.y*R.dcm4 + mag.z*R.dcm5;
//	Magn->z = mag.x*R.dcm6 + mag.y*R.dcm7 + mag.z*R.dcm8;
	/////////////////////////////////////////////////
	//	Gyro
	//Convert to rad/s
	Gyro->x	= ((float)gx - GyroBias.x*(*SampleTime))  / (float)EKFQUA_GYRO_Sensitivity * DEG_TO_RAD ;
	Gyro->y	= ((float)gy - GyroBias.y*(*SampleTime)) / (float)EKFQUA_GYRO_Sensitivity * DEG_TO_RAD;
	Gyro->z	= ((float)gz - GyroBias.z*(*SampleTime)) / (float)EKFQUA_GYRO_Sensitivity * DEG_TO_RAD;	
	/////////////////////////////////////////////////
	//	Acce
	//Convert 
	Acce->x	= ax ;
	Acce->y	= ay ;
	Acce->z	= az ;	
	Acce->x	/= (float)EKFQUA_ACCEL_Sensitivity * 10; //scale to 1 by dividing by 10
	Acce->y	/= (float)EKFQUA_ACCEL_Sensitivity * 10;
	Acce->z	/= (float)EKFQUA_ACCEL_Sensitivity * 10;		
	return READ;
}
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

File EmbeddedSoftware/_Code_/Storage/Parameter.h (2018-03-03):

#include "BoardConfig.h"

typedef enum
{
	PARAM_OK    						 ,
	PARAM_OverFloat					 ,
	PARAM_ModeConflict			 ,
	PARAM_EEPROM_WRITE_FAIL  ,
	PARAM_EEPROM_READ_FAIL 	 ,
}PARAMETER;

typedef enum
{	
	GYRO_BIAS_X    				= 1, 
	GYRO_BIAS_Y    				= 2, 
	GYRO_BIAS_Z    				= 3,  
	
	MAGN_OFFSET_X    			= 4, 
	MAGN_OFFSET_Y    			= 5, 
	MAGN_OFFSET_Z    			= 6,  
	
	MAGN_SCALEGAIN_X    	= 7, 
	MAGN_SCALEGAIN_Y    	= 8, 
	MAGN_SCALEGAIN_Z    	= 9, 
	
	MAGN_AXIS_X    				= 10, 
	MAGN_AXIS_Y    				= 11, 
	MAGN_AXIS_Z    				= 12, 
		
	COMP_X  							= 13, 
	COMP_Y     						= 14, 
	COMP_Z     						= 15, 

	AHRS_KP    						= 16, 
	AHRS_KI    						= 17, 

	KFDCM_R1	    				= 18, 		
	KFDCM_Q1							= 19, 
	KFDCM_R2	    				= 20, 		
	KFDCM_Q2							= 21, 
	
	THRS_ACCE 						= 22,
	THRS_GYRO 						= 23,
		
	aKFDCM_R1	    				= 24, 		
	aKFDCM_Q1							= 25, 
	aKFDCM_R2	    				= 26, 		
	aKFDCM_Q2							= 27, 

	FREQUENCY 						= 28, 
	
	
	PARA_TYPE_MIN   			= 1, 
	PARA_TYPE_MAX    			= 29,  //FREQUENCY+1
	PARA_TYPE_NONE  			= 30, 	
}PARAM_TYPE;

	#define AddrOffset 3
typedef enum
{
	PARA_MODE_0 =	0,		//  significand bytes 
	PARA_MODE_1 =	1 + AddrOffset,		//1 byte							//+-127
	PARA_MODE_2 =	2 + AddrOffset,		//2 bytes							//+=32767
	PARA_MODE_3 =	3 + AddrOffset,		//3 bytes							//+-8388607
	PARA_MODE_4 =	4 + AddrOffset		//4 bytes							//+-214748364
}BYTE_MODE;

#define PARA_RANGE_MODE_1				127
#define PARA_RANGE_MODE_2				32767
#define PARA_RANGE_MODE_3				8388607
#define PARA_RANGE_MODE_4				2147483647

#define PARA_RANGE_EXP					127
typedef struct 
{
	float	 			*Pointer;
	BYTE_MODE	 	mode;
	uint8_t     *BufAdd;
}FLOAT;

uint8_t PARAM_Buff_READ (PARAM_TYPE type, uint8_t pos);
extern int16_t PARAM_Read (uint8_t 	*Addr);
extern int16_t PARAM_Write (PARAM_TYPE type, uint8_t *Addr);
PARAMETER PARAM_EEPROM_WRITE (PARAM_TYPE Paratype);
PARAMETER PARAM_EEPROM_READ (void);
void Initialize_PARAMETER (uint8_t writeInit);
PARAMETER PARAM_VariableToSerial(PARAM_TYPE type);

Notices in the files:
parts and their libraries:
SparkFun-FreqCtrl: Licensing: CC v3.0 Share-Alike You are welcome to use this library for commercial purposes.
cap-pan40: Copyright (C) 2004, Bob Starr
